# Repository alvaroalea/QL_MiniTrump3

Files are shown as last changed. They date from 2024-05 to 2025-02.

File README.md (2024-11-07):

# SINCLAIR QL Mini Trump Card 3 Disk Interface

(C) 2024 Alvaro Alea Fernandez

License under: CERN Open Hardware Licence Version 2 - Strongly Reciprocal

https://ohwr.org/cern_ohl_s_v2.txt

This is a new PCB for the well know Trump Card Interface.

WARNING: This board include a joke (not in the preview picture, surprise!) in the back skillscreen, I'm not political, it's only a game of words, if you do not like, you can remove the back skillscreen when order the PCB or ask me for gerbers without the joke, no problem.

## Advantages

This PCB add a passthrough conector to allow aditional interfaces. (compatibility is limited, not al signal are routed and boards that use the P'N'P mechanism of the QL only work with a Minerva ROM because Sinclair's ROM only search for 1 board)

It's also a lot smaller than original one.

It's use standar AT cable (with a twist) and standar AT disc drives (drives configures as 2nd unit)

## Drawbacks

But it do not have memory, you need a Memory Expansion, be aware that you should use only a 512Kb (total 640Kb) expansion, if you want to have a total of 896Kb (like the original trump card) you should use my expansion board, and connect after the trump card, also JP1 in this board and the equivalent jumper shall be soldered to allow the paging mechanism of the Trump Card.

It only support 2 Disk Drive, no way to use 3 or 4 Drives

For the GAL use the one in the GAL directory, compatible with GAL16V8 and ATF16V8, it's compiled with GALasm that you can found here: https://github.com/daveho/GALasm

# Technical Info

It work with WD1770 and WD1772 floppy disc controlllers.

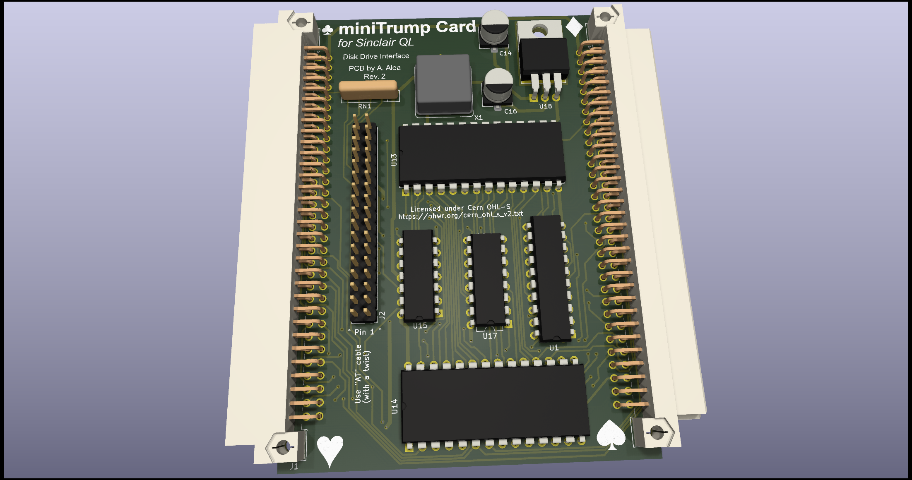
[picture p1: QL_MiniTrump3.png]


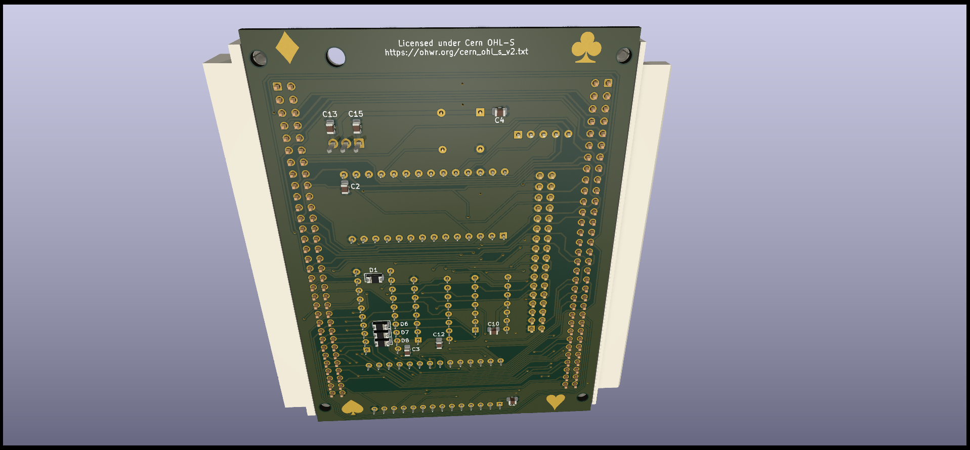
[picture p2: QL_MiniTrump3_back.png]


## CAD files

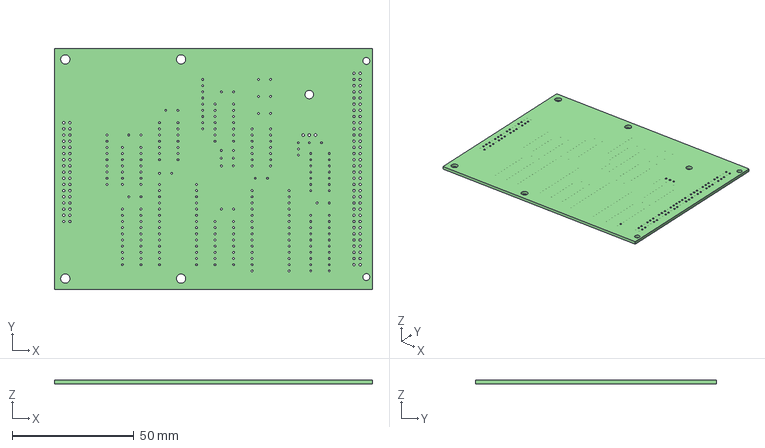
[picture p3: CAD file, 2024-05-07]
QL_MiniTrump3.step
130.8 x 99.1 x 1.60 mm

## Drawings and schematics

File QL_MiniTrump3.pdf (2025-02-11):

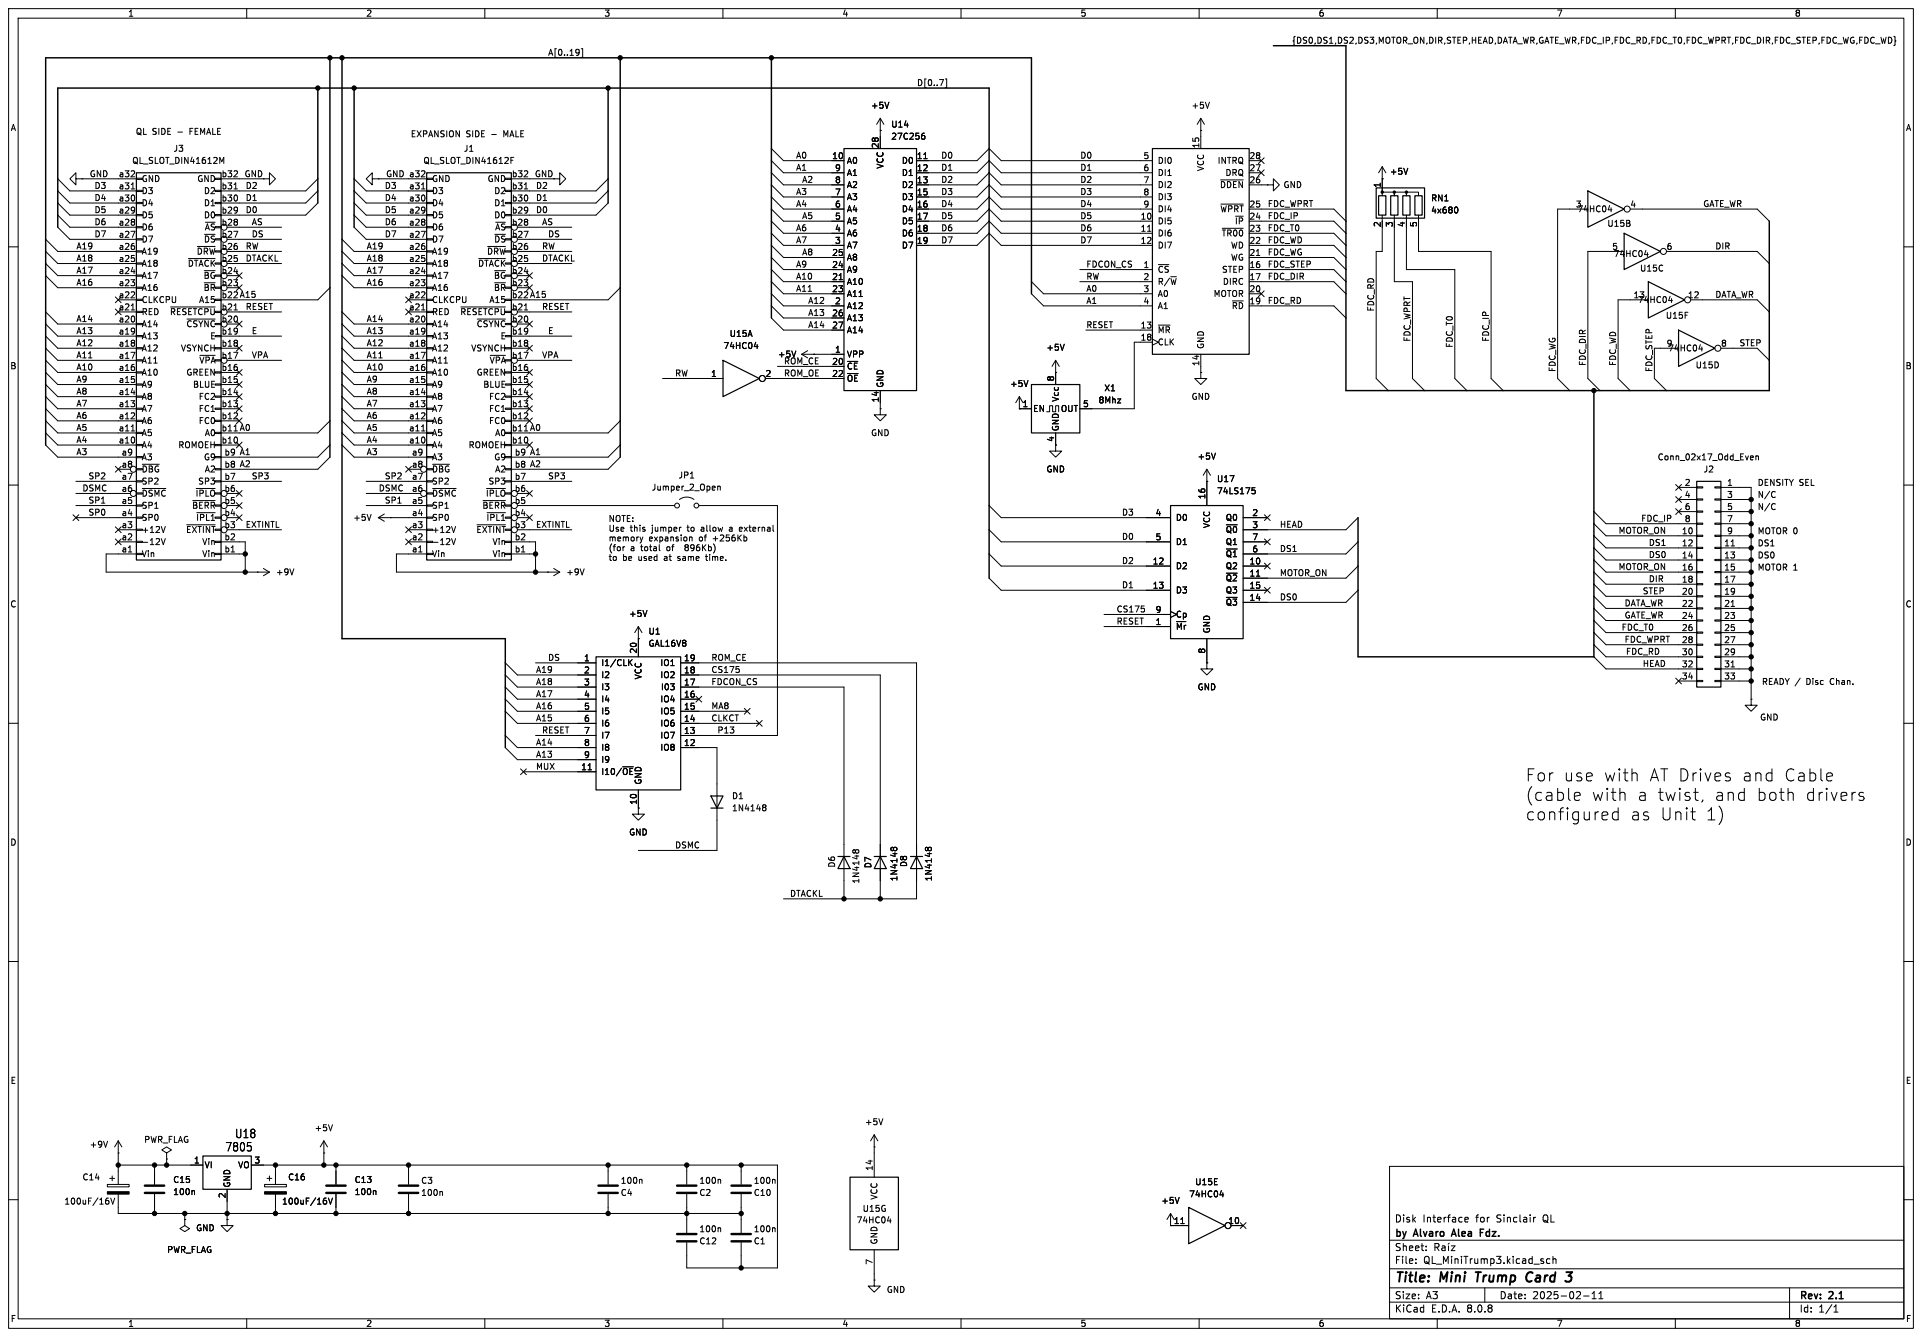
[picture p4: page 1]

b19 Vin b2 ~{CSYNC}b20 ~{RESETCPU}b21 A15 b22 ~{BR}b23 ~{BG}b24 ~{DTACK}b25 ~{DRW}b26 ~{DS}b27 ~{AS}b28 D0 b29 ~{EXTINT}b3 D1 b30 D2 b31 GND b32 ~{IPL1}b4 ~{BERR}b5 ~{IPLO}b6 SP3 b7 A2 b8 G9 b9

(cable with a twist, and both drivers

Id: 1/1 Title: Mini Trump Card 3

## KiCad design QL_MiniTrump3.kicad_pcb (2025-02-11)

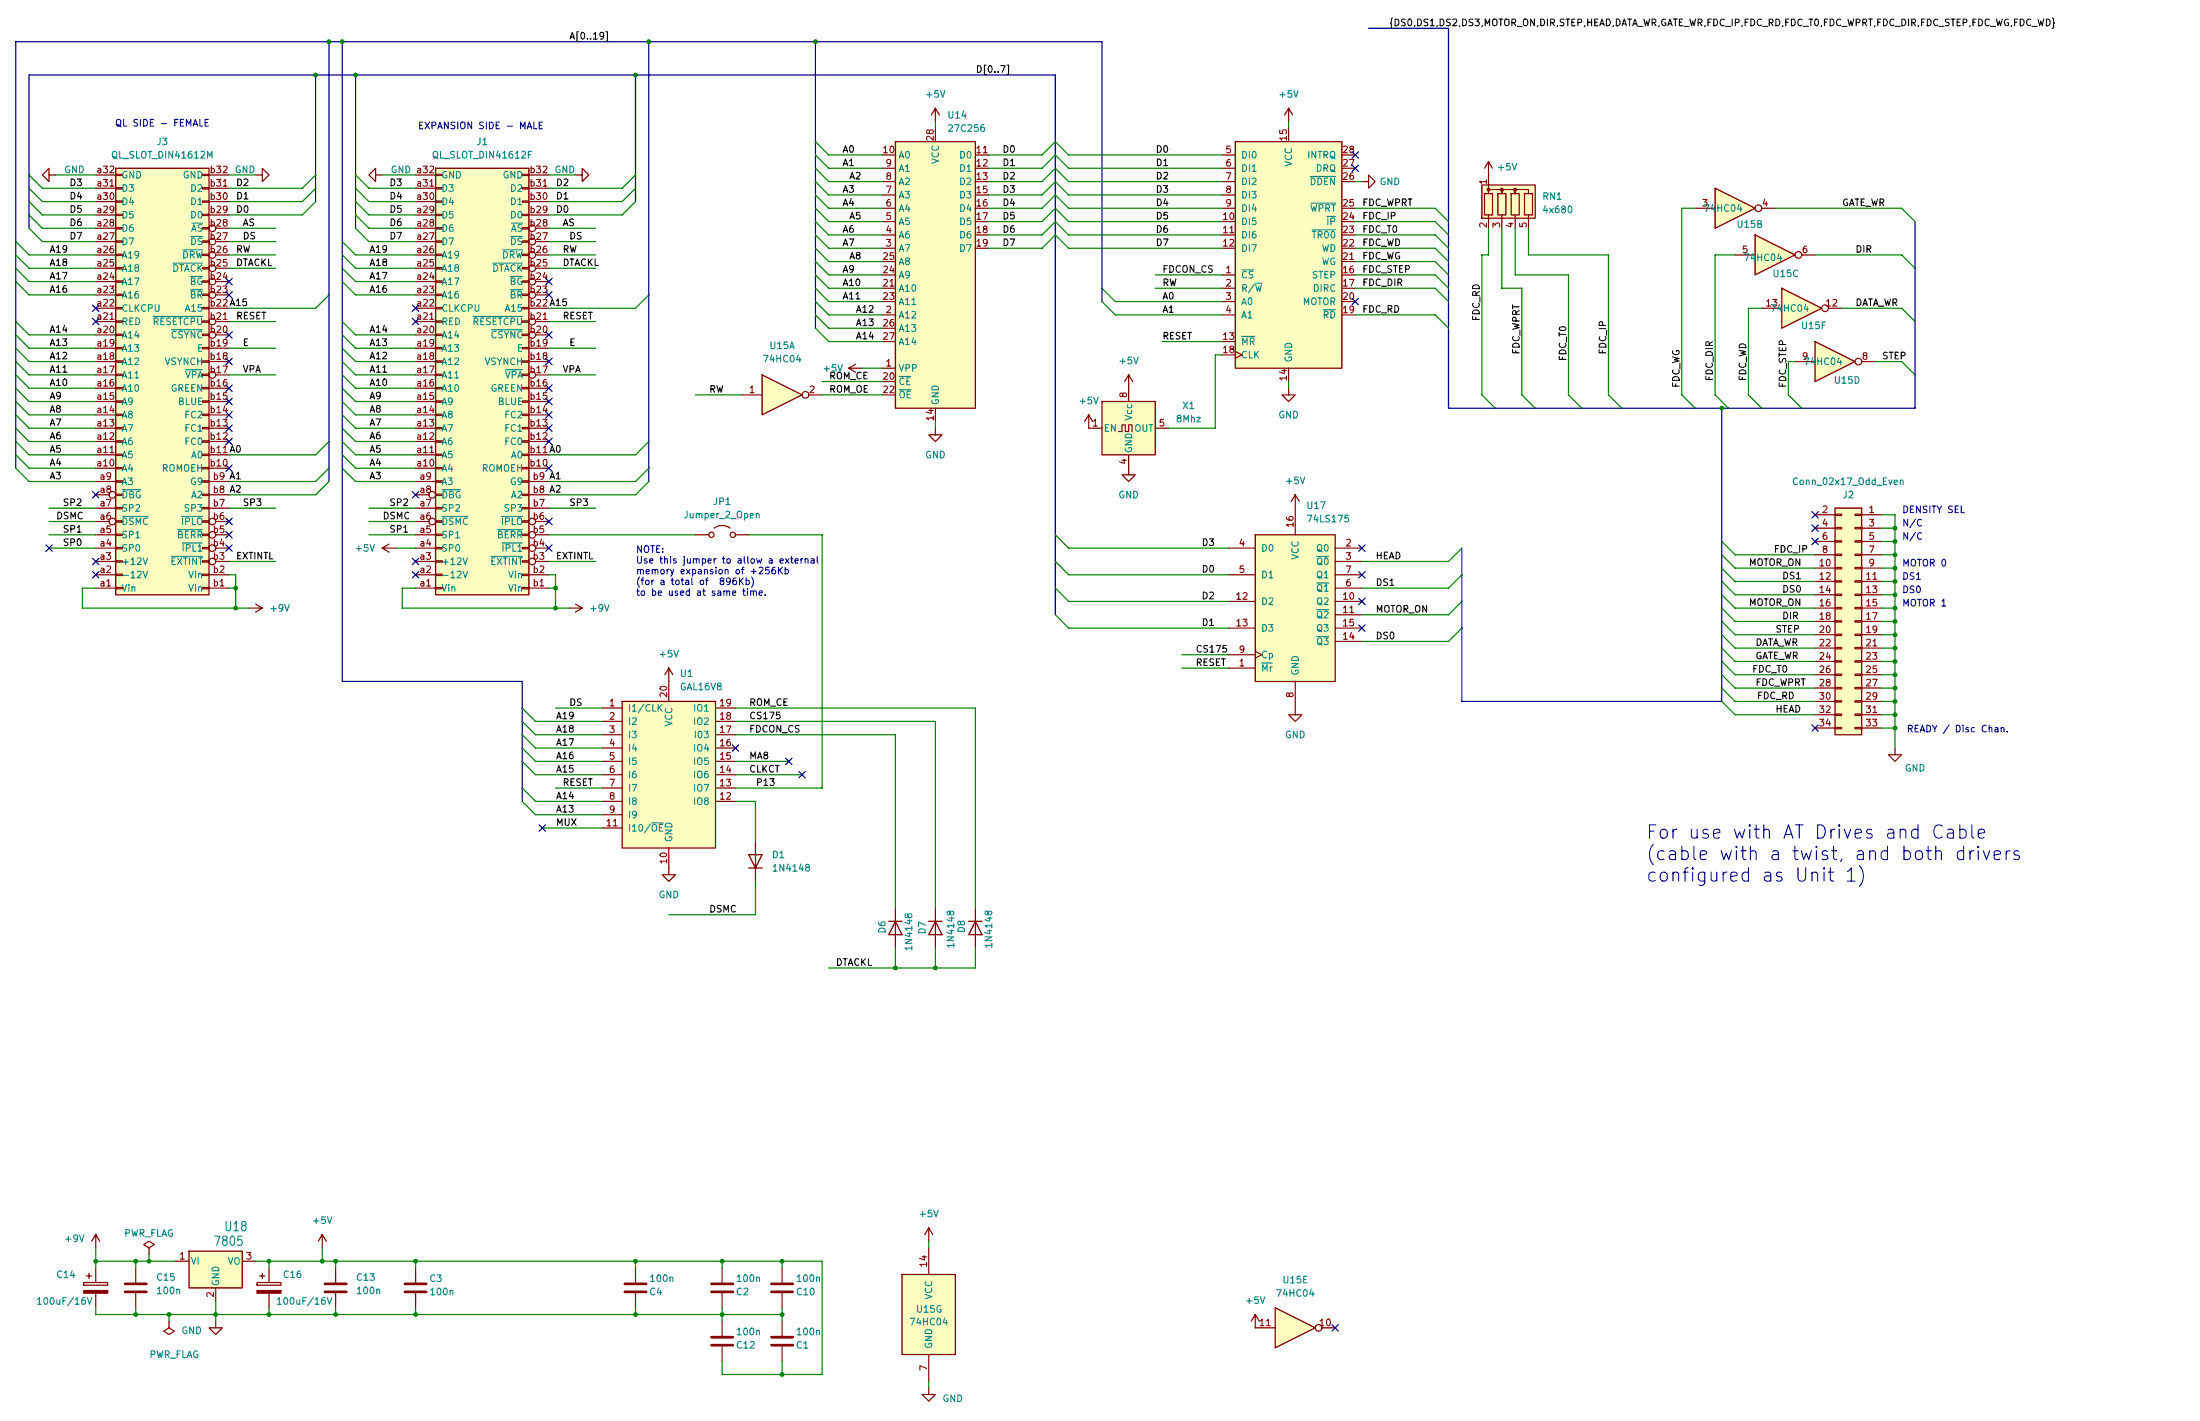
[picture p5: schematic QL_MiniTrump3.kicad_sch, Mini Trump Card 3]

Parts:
C1, C2, C3, C4, C10, C12, C13, C15: 100n; C_0805_2012Metric
C14, C16: 100uF/16V; CP_Elec_6.3x5.4
D1, D6, D7, D8: 1N4148; D_0805_2012Metric
J1: QL_SLOT_DIN41612F; DIN41612_B_2x32_Female_Horizontal_THT
J2: Conn_02x17_Odd_Even; PinHeader_2x17_P2.54mm_Vertical
J3: QL_SLOT_DIN41612M; DIN41612_B_2x32_Male_Horizontal_THT
JP1: Jumper_2_Open; SolderJumper-2_P1.3mm_Open_RoundedPad1.0x1.5mm
RN1: 4x680; R_Array_SIP5
U1: GAL16V8; DIP-20_W7.62mm
U13: FDC_WD1772; DIP-28_W15.24mm
U14: 27C256; DIP-28_W15.24mm
U15: 74HC04; DIP-14_W7.62mm
U17: 74LS175; DIP-16_W7.62mm
U18: 7805; TO-220-3_Horizontal_TabDown
X1: 8Mhz; Oscillator_DIP-8

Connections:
+5V: C1.1, C2.2, C3.2, C4.2, C10.2, C12.1, C13.1, C16.1, J1.a4 (SP0), RN1.1 (common), U1.20 (VCC), U13.15 (VCC), U14.1 (VPP), U14.28 (VCC), U15.11, U15.14 (VCC), U17.16 (VCC), U18.3 (VO), X1.1 (EN), X1.8 (Vcc)
+9V: C14.1, C15.1, J1.a1 (Vin), J1.b1 (Vin), J1.b2 (Vin), J3.a1 (Vin), J3.b1 (Vin), J3.b2 (Vin), U18.1 (VI)
/A0: J1.b11 (A0), J3.b11 (A0), U13.3 (A0), U14.10 (A0)
/A1: J1.b9 (G9), J3.b9 (G9), U13.4 (A1), U14.9 (A1)
/A2: J1.b8 (A2), J3.b8 (A2), U14.8 (A2)
/A3: J1.a9 (A3), J3.a9 (A3), U14.7 (A3)
/A4: J1.a10 (A4), J3.a10 (A4), U14.6 (A4)
/A5: J1.a11 (A5), J3.a11 (A5), U14.5 (A5)
/A6: J1.a12 (A6), J3.a12 (A6), U14.4 (A6)
/A7: J1.a13 (A7), J3.a13 (A7), U14.3 (A7)
/A8: J1.a14 (A8), J3.a14 (A8), U14.25 (A8)
/A9: J1.a15 (A9), J3.a15 (A9), U14.24 (A9)
/A10: J1.a16 (A10), J3.a16 (A10), U14.21 (A10)
/A11: J1.a17 (A11), J3.a17 (A11), U14.23 (A11)
/A12: J1.a18 (A12), J3.a18 (A12), U14.2 (A12)
/A13: J1.a19 (A13), J3.a19 (A13), U1.9 (I9), U14.26 (A13)
/A14: J1.a20 (A14), J3.a20 (A14), U1.8 (I8), U14.27 (A14)
/A15: J1.b22 (A15), J3.b22 (A15), U1.6 (I6)
/A16: J1.a23 (A16), J3.a23 (A16), U1.5 (I5)
/A17: J1.a24 (A17), J3.a24 (A17), U1.4 (I4)
/A18: J1.a25 (A18), J3.a25 (A18), U1.3 (I3)
/A19: J1.a26 (A19), J3.a26 (A19), U1.2 (I2)
/AS: J1.b28 (~AS), J3.b28 (~AS)
/CLKCT: U1.14 (IO6)
/CS175: D7.1 (K), U1.18 (IO2), U17.9 (Cp)
/D0: J1.b29 (D0), J3.b29 (D0), U13.5 (DI0), U14.11 (D0), U17.5 (D1)
/D1: J1.b30 (D1), J3.b30 (D1), U13.6 (DI1), U14.12 (D1), U17.13 (D3)
/D2: J1.b31 (D2), J3.b31 (D2), U13.7 (DI2), U14.13 (D2), U17.12 (D2)
/D3: J1.a31 (D3), J3.a31 (D3), U13.8 (DI3), U14.15 (D3), U17.4 (D0)
/D4: J1.a30 (D4), J3.a30 (D4), U13.9 (DI4), U14.16 (D4)
/D5: J1.a29 (D5), J3.a29 (D5), U13.10 (DI5), U14.17 (D5)
/D6: J1.a28 (D6), J3.a28 (D6), U13.11 (DI6), U14.18 (D6)
/D7: J1.a27 (D7), J3.a27 (D7), U13.12 (DI7), U14.19 (D7)
/DATA_WR: J2.22, U15.12
/DIR: J2.18, U15.6
/DS: J1.b27 (~DS), J3.b27 (~DS), U1.1 (I1/CLK)
/DS0: J2.14, U17.14 (~Q3)
/DS1: J2.12, U17.6 (~Q1)
/DSMC: D1.1 (K), J1.a6 (~DSMC), J3.a6 (~DSMC)
/DTACKL: D6.2 (A), D7.2 (A), D8.2 (A), J1.b25 (~DTACK), J3.b25 (~DTACK)
/E: J1.b19 (E), J3.b19 (E)
/EXTINTL: J1.b3 (~EXTINT), J3.b3 (~EXTINT)
/FDCON_CS: D6.1 (K), U1.17 (I03), U13.1 (~CS)
/FDC_DIR: U13.17 (DIRC), U15.5
/FDC_IP: J2.8, RN1.5 (R4), U13.24 (~IP)
/FDC_RD: J2.30, RN1.2 (R1), U13.19 (~RD)
/FDC_STEP: U13.16 (STEP), U15.9
/FDC_T0: J2.26, RN1.4 (R3), U13.23 (~TR00)
/FDC_WD: U13.22 (WD), U15.13
/FDC_WG: U13.21 (WG), U15.3
/FDC_WPRT: J2.28, RN1.3 (R2), U13.25 (~WPRT)
/GATE_WR: J2.24, U15.4
/HEAD: J2.32, U17.3 (~Q0)
/MA8: U1.15 (IO5)
/MOTOR_ON: J2.10, J2.16, U17.11 (~Q2)
/MUX: U1.11 (I10/~OE)
/P13: JP1.2 (B), U1.13 (IO7)
/RESET: J1.b21 (~RESETCPU), J3.b21 (~RESETCPU), U1.7 (I7), U13.13 (~MR), U17.1 (~Mr)
/ROM_CE: D8.1 (K), U1.19 (IO1), U14.20 (~CE)
/ROM_OE: U14.22 (~OE), U15.2
/RW: J1.b26 (~DRW), J3.b26 (~DRW), U13.2 (R/~W), U15.1
/SP0: J3.a4 (SP0)
/SP1: J1.a5 (SP1), J3.a5 (SP1)
/SP2: J1.a7 (SP2), J3.a7 (SP2)
/SP3: J1.b7 (SP3), J3.b7 (SP3)
/STEP: J2.20, U15.8
/VPA: J1.b17 (~VPA), J3.b17 (~VPA)
GND: C1.2, C2.1, C3.1, C4.1, C10.1, C12.2, C13.2, C14.2, C15.2, C16.2, J1.a32 (GND), J1.b32 (GND), J2.1, J2.3, J2.5, J2.7, J2.9, J2.11, J2.13, J2.15, J2.17, J2.19, J2.21, J2.23, J2.25, J2.27, J2.29, J2.31, J2.33, J3.a32 (GND), J3.b32 (GND), U1.10 (GND), U13.14 (GND), U13.26 (~DDEN), U14.14 (GND), U15.7 (GND), U17.8 (GND), U18.2 (GND), X1.4 (GND)
unnamed: D1.2 (A), U1.12 (IO8)
unnamed: J1.b5 (~BERR), JP1.1 (A)
unnamed: U13.18 (CLK), X1.5 (OUT)

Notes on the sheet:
QL SIDE - FEMALE
NOTE: Use this jumper to allow a external memory expansion of +256Kb (for a total of 896Kb) to be used at same time.
MOTOR 0
DS0
DS1
READY / Disc Chan.
MOTOR 1
N/C
For use with AT Drives and Cable (cable with a twist, and both drivers configured as Unit 1)
DENSITY SEL
EXPANSION SIDE - MALE

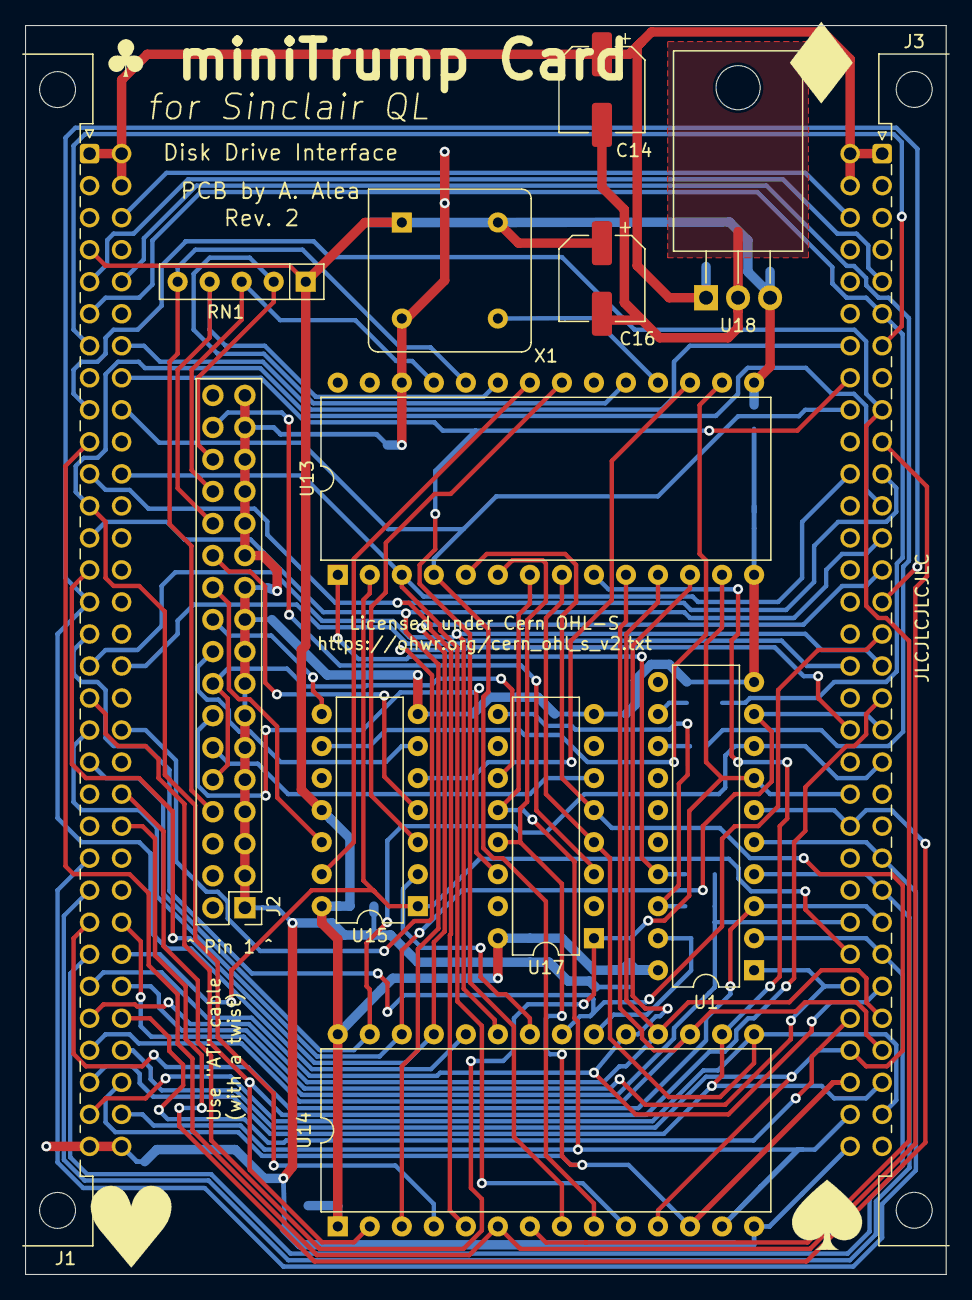
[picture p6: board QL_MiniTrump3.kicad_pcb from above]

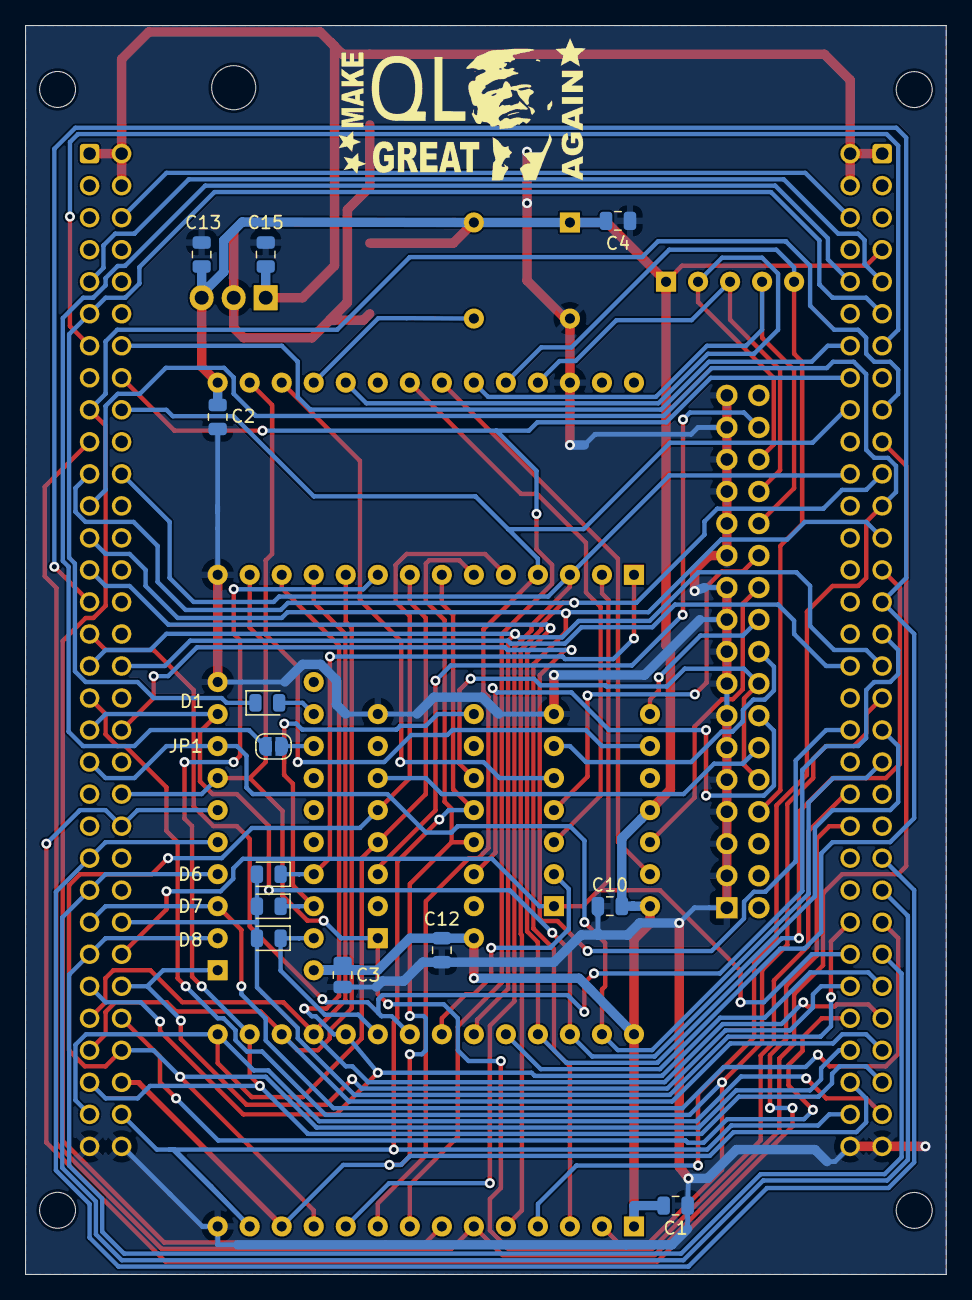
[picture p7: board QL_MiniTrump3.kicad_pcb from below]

Board: 2 copper layers, 73.0 x 99.1 mm, 26 parts (13 on the bottom side), 67 nets.

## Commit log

2024-05-07 real initial
    [QL_MiniTrump3-B_Cu.gbr, QL_MiniTrump3-B_Mask.gbr, QL_MiniTrump3-B_Silkscreen.gbr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]
2024-11-07 Rev 2, with GAL code
    [QL_MiniTrump3-B_Cu.gbr, QL_MiniTrump3-B_Mask.gbr, QL_MiniTrump3-B_Silks.gbr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]
2025-02-11 fix eprom reference, shall be 27C256
    [QL_MiniTrump3.kicad_pcb, QL_MiniTrump3.kicad_sch]

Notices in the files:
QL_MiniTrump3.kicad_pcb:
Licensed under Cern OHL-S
